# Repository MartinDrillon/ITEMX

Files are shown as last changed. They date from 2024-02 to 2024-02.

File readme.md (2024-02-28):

<h1 align="center">ITEMX</h1>

***

ITEMX est un clavier en deux parties de 46 touches fonctionnant avec [ZMK](https://github.com/zmkfirmware/zmk) et utilisant une SEEED XIAO BLE comme microcontrolleur. Il a été conçu avec [Ergogen](https://github.com/ergogen/ergogen), [FreeCad](https://www.freecad.org/) et [KiCad](https://www.kicad.org/).

C’est la quatrième itération d’un projet dont le but est de créer un clavier ergonomique ayant 5 touches de pouces par main et utilisant une répartition des caractères adaptés du [BÉPO](https://bepo.fr/wiki/Accueil).

_Bien que cette version soit parfaitement fonctionnelle, il demeure quelques défauts. Une cinquième version devrait voir le jour prochainement._

***

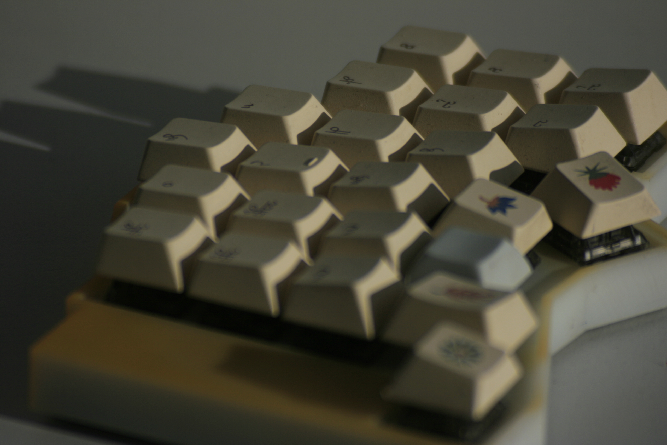
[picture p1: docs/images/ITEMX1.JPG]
ITEMX


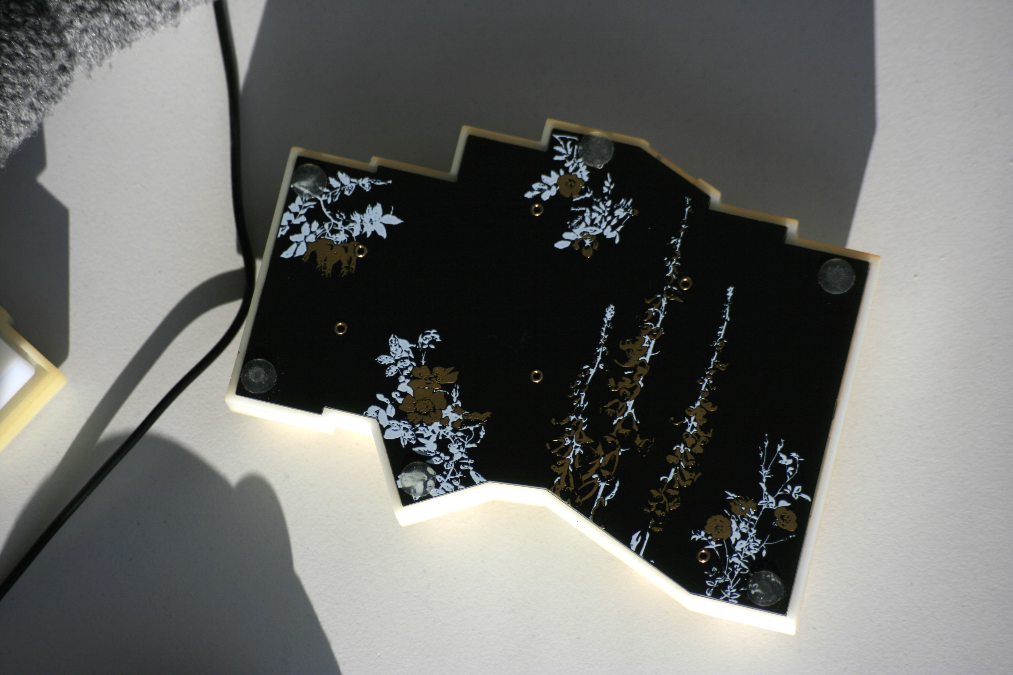
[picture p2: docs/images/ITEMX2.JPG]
ITEMX2


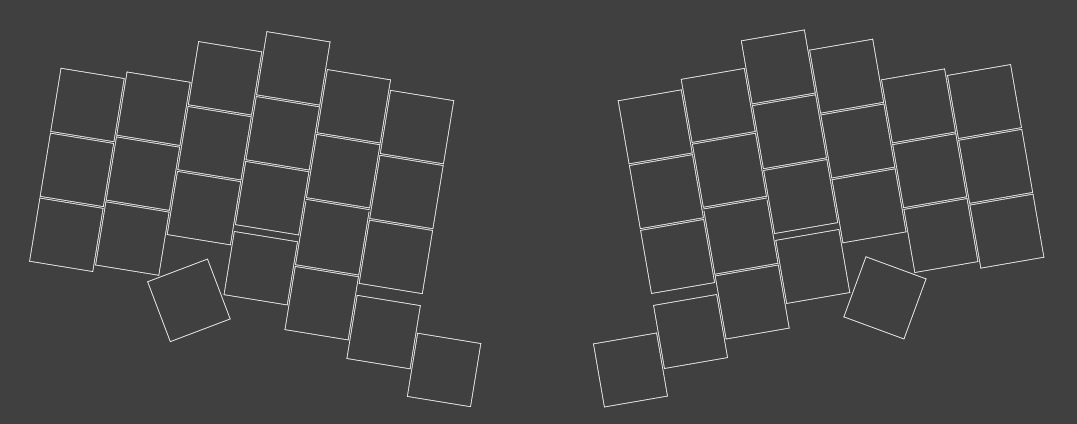
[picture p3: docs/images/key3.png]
ITEMX3


***

Ce clavier fonctionne avec une disposition dérivée du BÉPO. Pour être exact, il s’agit d’une adaptation du travail de Kawamashi publié [ici](https://forum.bepo.fr/viewtopic.php?id=1696). Après presque deux ans d’utilisation, il ne fait aucun doute pour moi que cette disposition est très largement supérieure à l’azerty pour la frappe du français (et de tout type de langage), autant en termes de confort que de rapidité. Le seul avantage indéniable à l’azerty est celui de l’habitude et de la relative difficulté à apprendre une nouvelle disposition.

Sa particularité, par rapport à d’autres claviers ergonomiques ([KYRIA](https://github.com/foostan/crkbd), [LILY58](https://github.com/kata0510/Lily58)...) dont il s’inspire, est d’avoir au total 10 touches de pouces toutes accessibles en déplaçant uniquement le doigt et non l’ensemble de la main (touch typing). Une touche de pouce spécifique peut être attribuée pour chaque modifiers de base (shift, ctrl, alt pour la main gauche et shift, altgr, win pour la droite) en plus de quelques caractères fréquents. Cela permet d’utiliser la moitié gauche du clavier comme un macropad lors de l’utilisation de logiciels de DAO/CAO nécessitant un usage intensif de combinaison à base de schift, ctrl, alt, alt+ctrl plus simplement qu’avec l’usage de mod-tap, hold-tap, homerows mods... (voir la documentation de [ZMK](https://zmk.dev/docs) sur les comportements possibles)

***

## DISPOSITION DES CARACTÈRES

**Niveau de base**

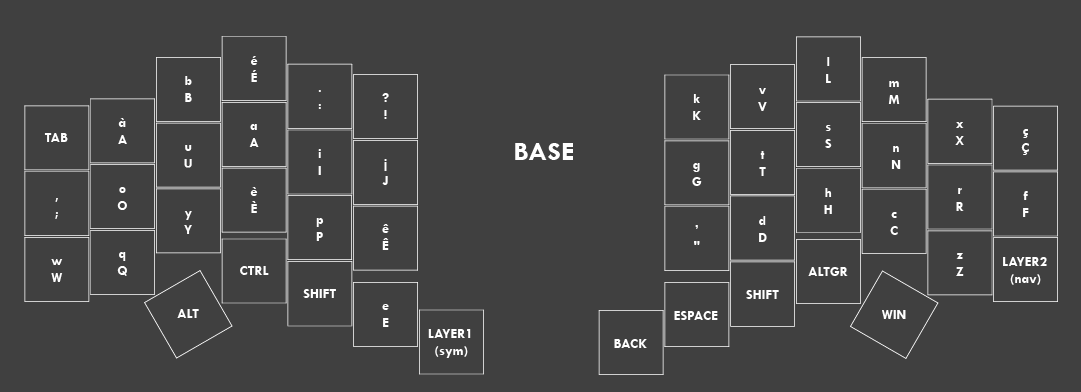
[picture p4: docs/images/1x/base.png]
BASE


**Cumbo**

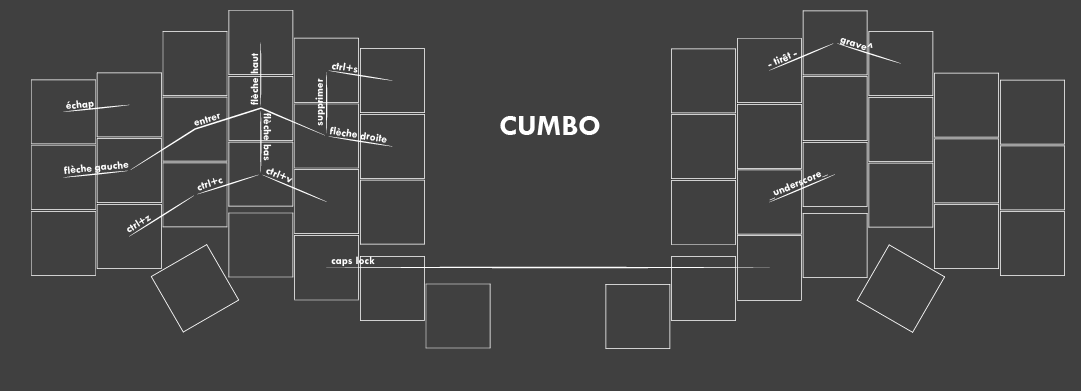
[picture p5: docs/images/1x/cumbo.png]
CUMBO


**Symbole**

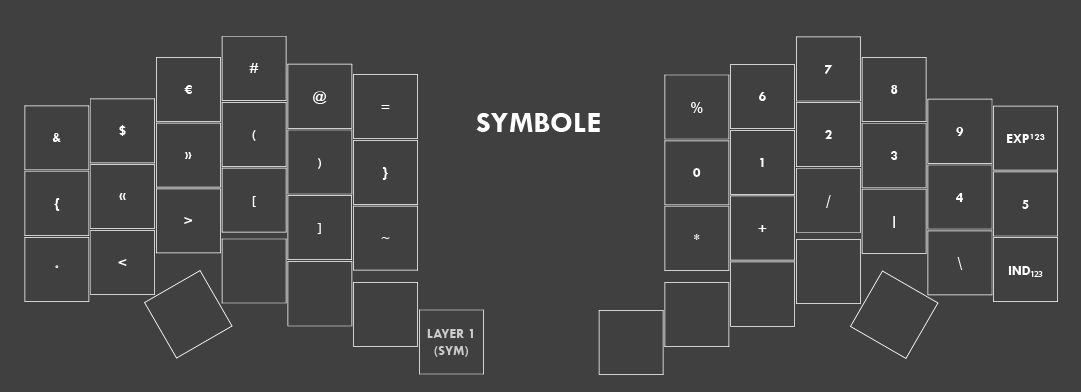
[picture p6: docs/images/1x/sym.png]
SYM


**Navigation**

_Visualisation à venir._

***

## UTILISATION DU BÉPO AVEC ZMK

Contrairement à QMK, ZMK ne propose pas de fichier à inclure dans le ficher keymap pour le faire correspondre au driver du clavier qu’utilise votre ordinateur (ici le [fichier](https://github.com/qmk/qmk_firmware/blob/master/quantum/keymap_extras/keymap_bepo.h) QMK permettant d’écrire un keymap en BÉPO). Sans rentrer dans les détails techniques, sans celui-ci, lorsque votre ordinateur utilise un driver BÉPO, le keycodes &kp Z est traduit en B et &kp B en k.

J’ai donc écris le fichier équivalent pour ZMK : [keys_bepo.h](https://github.com/MartinDrillon/zmk-config-ITEMX/blob/main/config/keys_bepo.h). Son but est de définir un second keycode plus lisible pour les caractères spécifiques au BÉPO. Lorsqu’il est inclu au keymap, il sera possible d'utiliser ou bien &kp Z ou bien &kp BP_B pour taper B sur un ordinateur utilisant un driver BÉPO. La liste de tous ces codes se trouve dans le fichier en question.

Voici le repository à copier si vous souhaitez créer votre propre keymap pour ce clavier ou vous en inspirer : [ZMK](https://github.com/MartinDrillon/zmk-config-ITEMX).

***

## AMÉLIORATION PRÉVUE SUR LA VERSION À VENIR

- Ajustement du placement de certaines touches de pouces.
- Faciliter la construction, en particulier au niveau de l’intégration de la XIAO SEEED.
- Amélioration du design de la coque.
- Publication d’un guide de construction adapté.

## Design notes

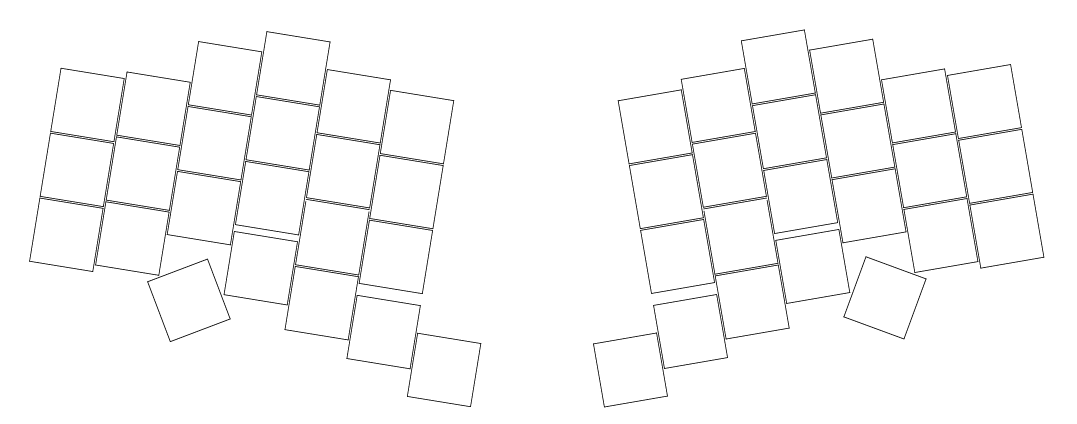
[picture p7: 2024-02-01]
docs/images/Key.png

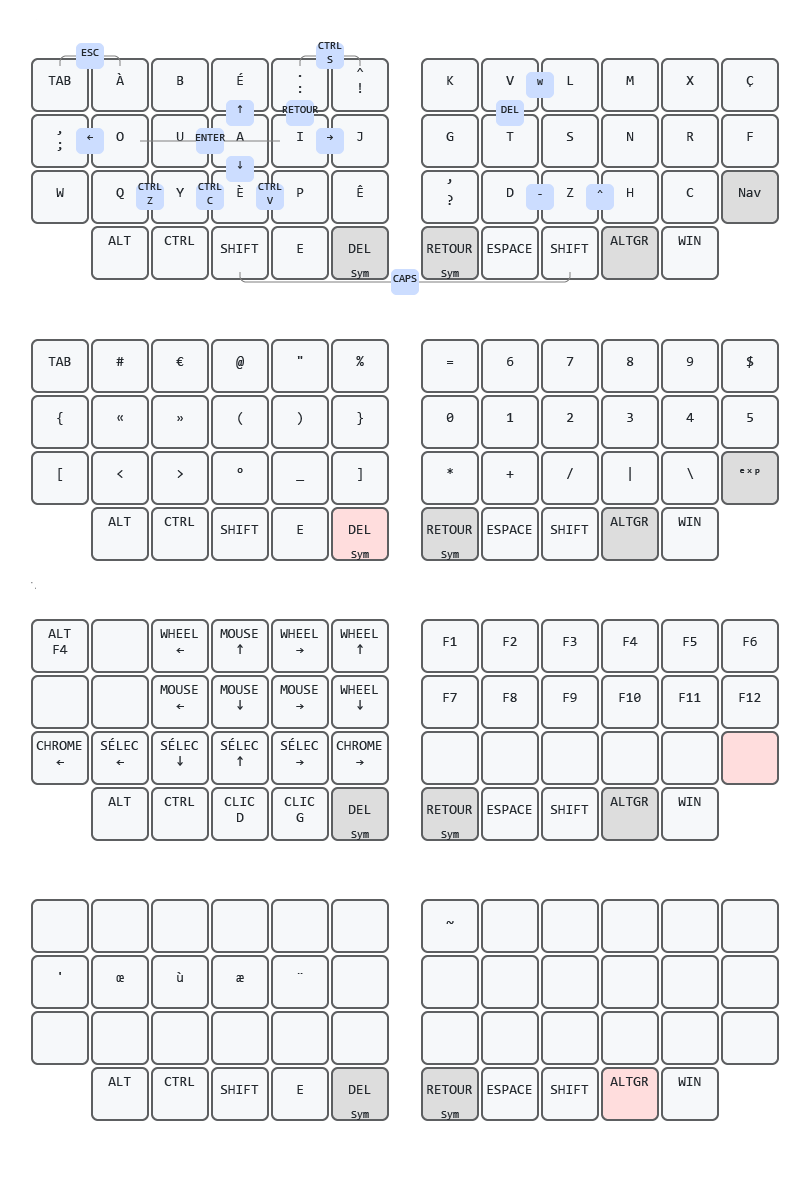
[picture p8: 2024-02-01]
docs/images/keymap1.png

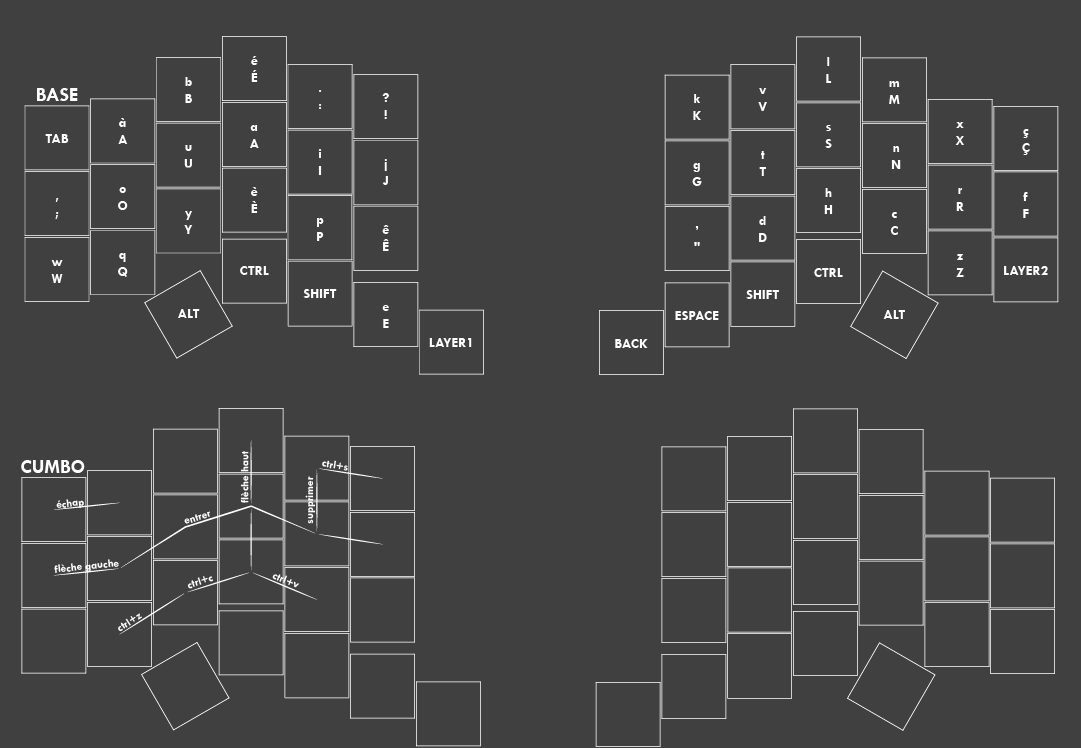
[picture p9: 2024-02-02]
docs/images/keymap2.png

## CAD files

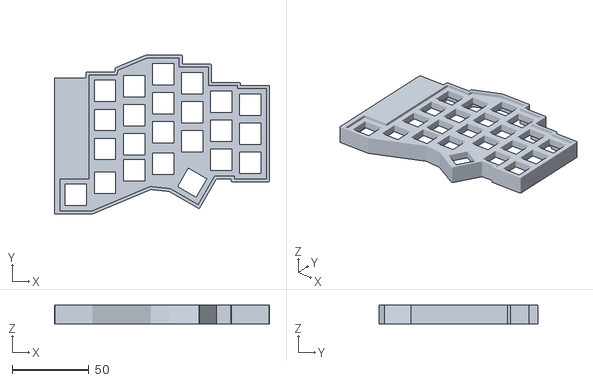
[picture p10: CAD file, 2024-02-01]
CASE/iteMX_case_droit.stl
140.5 x 104.0 x 12.1

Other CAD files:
CASE/iteMX_case_gauche.stl

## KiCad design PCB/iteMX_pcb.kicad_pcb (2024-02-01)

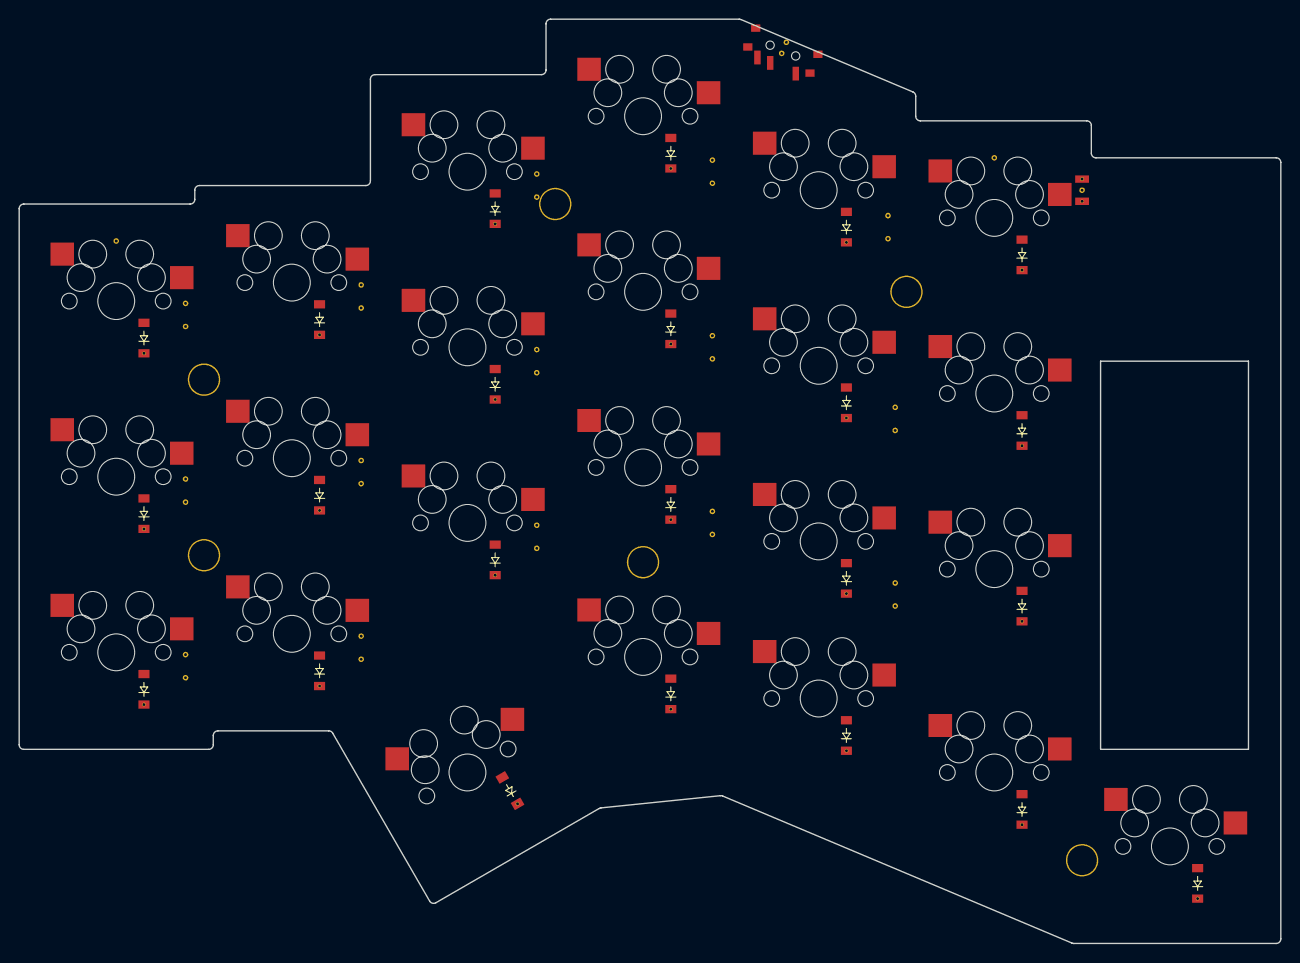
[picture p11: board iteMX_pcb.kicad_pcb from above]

Board: 2 copper layers, 136.5 x 100.0 mm, 47 parts (0 on the bottom side), 34 nets, no tracks yet.

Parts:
D1, D2, D3, D4, D5, D6, D7, D8, D9, D10, D11, D12, D13, D14, D15, D16, D17, D18, D19, D20, D21, D22, D23: diode_via
D25: connecteur_batterie
S1, S2, S3, S4, S5, S6, S7, S8, S9, S10, S11, S12, S13, S14, S15, S16, S17, S18, S19, S20, S21, S22, S23: mx_hotswapp

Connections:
GND: D25.1, D25.2
alt_first: D19.2, S19.1
col_1: S1.2, S2.2, S3.2
col_2: S4.2, S5.2, S6.2, S19.2
col_3: S7.2, S8.2, S9.2, S20.2
col_4: S10.2, S11.2, S12.2, S21.2
col_5: S13.2, S14.2, S15.2, S22.2
col_6: S16.2, S17.2, S18.2, S23.2
ctrl_first: D20.2, S20.1
e_first: D22.2, S22.1
index_bottom: D13.2, S13.1
index_home: D14.2, S14.1
index_top: D15.2, S15.1
inner_bottom: D16.2, S16.1
inner_home: D17.2, S17.1
inner_top: D18.2, S18.1
layer_first: D23.2, S23.1
middle_bottom: D10.2, S10.1
middle_home: D11.2, S11.1
middle_top: D12.2, S12.1
outer_bottom: D1.2, S1.1
outer_home: D2.2, S2.1
outer_top: D3.2, S3.1
pinkie_bottom: D4.2, S4.1
pinkie_home: D5.2, S5.1
pinkie_top: D6.2, S6.1
pos: D25.1, D25.2
ring_bottom: D7.2, S7.1
ring_home: D8.2, S8.1
ring_top: D9.2, S9.1
row_1: D3.1, D6.1, D9.1, D12.1, D15.1, D18.1
row_2: D2.1, D5.1, D8.1, D11.1, D14.1, D17.1
row_3: D1.1, D4.1, D7.1, D10.1, D13.1, D16.1
row_4: D19.1, D20.1, D21.1, D22.1, D23.1
shift_first: D21.2, S21.1

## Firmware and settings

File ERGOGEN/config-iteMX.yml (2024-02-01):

units: 
  xix: 17.5
  xiy: 20

points:
  key:
    padding: u
    tags: 
      1u: true
    footprints:
      mx_hotswap:
        type: mx
        params:
          hotswap: true
          reverse: true
          keycaps: true
        nets:
          # from: col_1
          # to: col_3
          from: =colrow
          to: =column_net
      diode:
        type: diodevia
        nets:
          # from: col_4
          # to: col_5
          from: =colrow
          to: =row_net
        anchor:
          shift: [3, -4]   
          rotate: 90

  zones:
    board:
      rows:
        bottom:
          row_net: row_3
        home:
          row_net: row_2
        top:
          row_net: row_1

      columns:
        outer:
          key:
            column_net: col_1
          rows:
            bottom:
              bind: [1,1,1,1] # Haut,Gauche,Bas,Droit
            home:
              bind: [1,1,1,1]
            top: 
              bind: [1,1,1,1]
            

        pinkie:
          stagger: 2
          spread: u
          key:
            column_net: col_2
          rows:
            bottom:
              bind: [1,1,1,1] # Haut,Gauche,Bas,Droit
            home:
              bind: [1,1,1,1]
            top: 
              bind: [1,1,1,1]
            
        ring:
          stagger: 12
          spread: u
          key:
            column_net: col_3
          rows:
            bottom:
              bind: [1,1,10,1] # Haut,Gauche,Bas,Droit
            home:
              bind: [1,1,1,1]
            top: 
              bind: [1,3,1,1]

        middle:
          stagger: 6
          spread: u
          origin: [0,-19]
          key:  
            column_net: col_4
          rows:
            bottom:
              bind: [1,1,5,1] # Haut,Gauche,Bas,Droit
            home:
              bind: [1,1,1,1]
            top: 
              bind: [1,1,1,1]
          
                   
        index:
          stagger: -8
          spread: u
          origin: [0,-19]
          key: 
            column_net: col_5
          rows:
            bottom:
              bind: [1,1,1,1] # Haut,Gauche,Bas,Droit
            home:
              bind: [1,1,1,5]
            top: 
              bind: [1,1,1,5]


        inner:
          stagger: -3
          spread: u
          key: 
            column_net: col_6
          rows:
            bottom:
              bind: [1,1,5,1] # Haut,Gauche,Bas,Droit
            home:
              bind: [1,1,1,1]
            top: 
              bind: [1,1,1,1]

    thumb:
      anchor:
        ref: board_ring_bottom
        shift: [0,-27]

      rows:
        first:
          row_net: row_4

      columns:
        alt: 
          key:
            column_net: col_2
          rows: 
            first:
              rotate: 30
              bind: [5,1,1,1] 

        ctrl:
          stagger: 12.5
          spread: u
          key:
            column_net: col_3
          rows: 
            first:  
              bind: [1,1,1,10] 

        shift:
          stagger: -4.5
          spread: u
          key: 
            column_net: col_4
          rows: 
            first:
              bind: [1,1,1,1] 

        e: 
          spread: u
          stagger: -8
          key: 
            column_net: col_5
          rows: 
            first:
              bind: [1,1,1,1] # Avec la rotation : Droite,Haut,Gauche,Bas

        layer:
          stagger: -8
          spread: u
          key: 
            column_net: col_6
          rows: 
            first:
              bind: [1,1,1,1] 

outlines:
  exports:

### TOUCHES TOUCHES TOUCHES TOUCHES TOUCHES TOUCHES TOUCHES TOUCHES TOUCHES TOUCHES TOUCHES TOUCHES TOUCHES TOUCHES TOUCHES TOUCHES ###

    keys: #1u
      - type: keys
        side: left
        size: [1u - 0.5, 1u - 0.5] # Choc keycaps are 17.5 x 16.5
        bound: false
        tags: [1u]

    keysspace: #1u
      - type: keys
        side: left
        size: [18.5, 17.5] # Choc keycaps are 17.5 x 16.5
        bound: false

    keyscase: #1u
      - type: keys
        side: left
        size: [15.5, 15.5] # Choc keycaps are 17.5 x 16.5
        bound: false

    bind: 
      - type: keys
        side: left
        size: [u, u]
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

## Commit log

2024-02-01 création des dossiers
2024-02-01 ajout pcb
    [iteMX_pcb.kicad_pcb, iteMX_top.kicad_pcb]
2024-02-01 ajout gerber, ergogen et case
    [iteMX_bottom-B_Cu.gbr, iteMX_bottom-B_Mask.gbr, iteMX_bottom-B_Paste.gbr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]
